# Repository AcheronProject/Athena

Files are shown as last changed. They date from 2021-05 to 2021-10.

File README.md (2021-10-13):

# Acheron Athena

## Introduction

Athena is a tenkeyless (TKL) keyboard Printed Circuit Board (PCB) which main feature is the multi-layout support. Athena supports:

- 87 (F12) or 88 (F13) TKL function rows;
- ANSI and ISO layouts
- 7U and 6.25U spacebar bottom row layouts
- Split backspace
- Split right shift

Below is a [Keyboard Layout Editor](http://keyboard-layout-editor.com/) image of the layouts Athena supports.

Athena KLE

In [this link](https://raw.githubusercontent.com/Gondolindrim/file_hosting/main/athena/athena_KLE.json) there is a KLE JSON file for the layout.

Both Apollo and Athena line of PCBs were designed to be "universal" TKL PCBs, that is, designed to fit a wide variety of custom mechanical keyboards. The compatibility list is being built as more people check and test. See the **Keyboard compatibility** section of this README for the available list.

## Technical information

- Layout size: tenkeykess (TKL)
- Compatible switches: MX-like only, solderable
- Lighting: single colors per-key through-hole LEDs, RGB underglow
- Microcontroller: STM32 family (see [the Joker topologyt documentaton](https://acheronproject.com/multimcu_article/multimcu_article/))
- Connector: detachable USB Type C on the top side and JST connector for daughterboard support
- Firmware compatibility: QMK (with VIA support)
- Protection hardware:
  * USB data lines and power rail ESD suppressing
  * USB power overvoltage protection
  * Enclosure grounding pad
  * Overcurrent protection
  * LDO crowbar diode
  * EMI suppression (shielding ferrite bead)
- Current release: release Alpha-RC1 (pre-release candidate)
- Designer: Gondolindrim
- License: Acheron Open-Source Hardware License version 1.3

## Keyboard compatibility

## Known compatibilities

- **Geonworks F1-8X and F1-6X:** confirmed by Geon, who tested the PCB 3D files against the case 3D files. Live hardware testing into a machined case is pending.

### Known incompatibilities

- **ai03 KBD8X MKII**: ai03 open-sourced the PCB files for his KBD8X. Alghtough Apollo's edges do fit inside the original PCB's, its connector is more protruded then the original PCB's.

- **PrismA18**: different layouts on the function row.

## Acknowledgements

- Geon, who kindly spent time helping design this PCB to fit his keyboards.

## Copyright notice

This project is released under the Acheron Open-Hardware License V1.3. For the license, please refer to the LICENCE.md file.

The "athena with shield" logo was licensed through Adobe Stock in [this link](https://stock.adobe.com/hu/images/greek-goddess-athena-illustration/157297137); the source file in Adobe Illustrator format, with a converted ``.svg`` format  can be found in ``./resources/athena_logo``. The license was obtained in may 06, 2021 and allows the AcheronProject to redistribute the logo as open-source and allows anyone to sell the PCBs commercially, but it does not allow for reproduction, meaning that if you want to use the logo for your designs or products you will have to buy a license yourself.

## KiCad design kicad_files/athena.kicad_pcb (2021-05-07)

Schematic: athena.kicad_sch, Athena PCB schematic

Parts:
C1, C2, C7: 100n; C_0805_2012Metric
C3, C4, C5, C13: 100n; C_0402_1005Metric
C6, C14: 4.7u; C_0402_1005Metric
C8: 1u; C_0402_1005Metric
C9: 10n; C_0402_1005Metric
C10, C11: 1u; CP_EIA-3216-10_Kemet-I_Pad1.58x1.35mm_HandSolder
C12: 10u; C_0805_2012Metric
D1, D2, D3, D4, D5, D6, D7, D8, D9, D10, D11, D12, D13, D14, D15, D16, D17, D18, D19, D20, D21, D22, D23, D24, D25, D26, D27, D28, D29, D30, D31, D32, D33, D34, D35, D36, D37, D38, D39, D40, D41, D42, D43, D44, D45, D46, D47, D48, D49, D50, D51, D52, D53, D54, D55, D56, D57, D58, D59, D60, D61, D62, D63, D64, D65, D66, D67, D68, D69, D70, D71, D72, D73, D74, D75, D76, D77, D78, D79, D80, D81, D82, D83, D84, D85, D86, D87, D88, D89, D90, D91, D92, D94: 1N4148W; D_SOD-123
D93: RB060M-60TR; D_SOD-123; Manufacturer Part Number RB060M-60TR; LCSC Part Number C114257
F1: mSMD110-16V; Fuse_1812_4532Metric; Manufacturer Part Number mSMD110-16V; LCSC Part Number C69691
FB1: CBW201209U121T; L_0805_2012Metric; Manufacturer Part Number CBW201209U121T; LCSC Part Number C139186
H1: MountingHole; MountingHole_2.5x4.0mm
J1, J3: SM04B-SRSS-TB(LF)(SN); SM04B-SRSS-TB(LF)(SN)_mounting-reliefs; Manufacturer Part Number SM04B-SRSS-TB(LF)(SN); LCSC Part Number C160404
J2: TYPE-C-31-M12; TYPE-C-31-M-12; Manufacturer Part Number TYPE-C-31-M-12; LCSC Part Number C165948
J4: ARM JTAG; Conn_ARM_JTAG_SWD_6
J5: EXTRA PINS; PinHeader_1x5_P2.54mm_Vertical
Q1: DTC123JKAT146; SOT-23; Manufacturer Part Number DTC123JKAT146; LCSC Part Number C111724
R1: 10k; R_0805_2012Metric
R2, R3: 5.1k; R_0805_2012Metric
R4, R5: 1.5k; R_0402_1005Metric
R6: 100R; R_0805_2012Metric
R7, R8: 100k; R_0805_2012Metric
R9: 330k; R_0805_2012Metric
R10: 1M; R_0805_2012Metric
SW1, SW2, SW3, SW4, SW5, SW6, SW7, SW8, SW9, SW10, SW11, SW12, SW13, SW14, SW15, SW16, SW17, SW18, SW19, SW20, SW21, SW22, SW23, SW24, SW25, SW26, SW27, SW28, SW29, SW30, SW31, SW32, SW33, SW34, SW35, SW36, SW37, SW38, SW40, SW41, SW43, SW44, SW45, SW46, SW47, SW48, SW49, SW50, SW51, SW52, SW53, SW54, SW56, SW57, SW58, SW60, SW61, SW62, SW63, SW64, SW65, SW66, SW67, SW68, SW69, SW70, SW71, SW73, SW74, SW75, SW79, SW80, SW81, SW82, SW83, SW84, SW85, SW86, SW87, SW88, SW89, SW91, SW92, SW103, SW104, SW105, SW107, SW111: MX Switch; MX100
SW39: MX Switch; MX200
SW42, SW55, SW106, SW108, SW110, SW112: MX Switch; MX150
SW59, SW93: MX Switch; MX175
SW72: MX Switch; MX225R
SW76, SW94, SW95, SW96, SW97, SW99, SW100, SW101, SW102: MX Switch; MX125
SW77: MX Switch; MX_ISOEnter_Horizontal
SW78: MX Switch; MX225
SW90: MX Switch; MX275
SW98: MX Switch; MX625R
SW109: MX Switch; MX700R
SW113: K2-1187SQ-A4SW-06; Manufacturer Part Number K2-1187SQ-A4SW-06; LCSC Part Number C92584
U1: TXS0101DBVR; SOT-23-6; Manufacturer Part Number TXS0101DBVR; LCSC Part Number C132604
U2: USBLC6-2SC6; SOT-23-6; Manufacturer Part Number USBLC6-2SC6; LCSC Part Number C7519
U3: STM32F072CBT6; LQFP-48_7x7mm_P0.5mm; Manufacturer Part Number STM32F072CBT6; LCSC Part Number C81720
U4: MCP1700T-3302E/TT; SOT-23; Manufacturer Part Number MCP1700T-3302E/TT; LCSC Part Number C39051

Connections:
3V3: C1.2, C3.1, C4.1, C5.2, C6.2, C8.1, C9.1, C11.1, C13.2, C14.2, D93.2 (A), J4.1, J5.4, R1.1, R4.1, R5.1, R8.1, SW113.1 (A), U1.1 (VCCA), U3.1 (VBAT), U3.9 (VDDA), U3.24 (VDD), U3.36 (VDDIO2), U3.48 (VDD), U4.2 (VO)
5V: C2.1, C10.1, D93.1 (K), F1.2, J1.1, J3.1, R7.1, U1.6 (VCCB), U4.3 (VI)
BOOT0: C12.2, J4.6, R9.2, R10.2, U3.44 (BOOT0)
C0: SW1.2, SW26.2, SW42.2, SW59.2, SW76.1, SW78.2, SW94.2, SW95.2, SW106.2, U3.16 (PA6/ADC_IN6/TIM3_CH1/TIM16_CH1)
C1: SW2.1, SW27.1, SW43.1, SW60.1, SW79.1, SW96.1, SW107.1, U3.15 (PA5/ADC_IN5/DAC_OUT2)
C2: SW3.1, SW18.2, SW28.1, SW44.1, SW61.1, SW80.1, SW97.1, SW108.1, U3.14 (PA4/TIM14_CH1/ADC_IN4)
C3: SW4.1, SW19.2, SW29.1, SW45.1, SW62.1, SW81.1, U3.13 (PA3/TIM15_CH2/ADC_IN3)
C4: SW5.1, SW20.2, SW30.1, SW46.1, SW63.1, SW82.1, U3.12 (PA2/ADC_IN2)
C5: SW6.1, SW21.2, SW31.1, SW47.1, SW64.1, SW83.1, U3.40 (SPI1_MISO/I2S1_MCK/TIM3_CH1/PB4)
C6: SW7.1, SW32.1, SW48.1, SW65.1, SW84.1, SW98.2, SW109.2, U3.39 (SPI1_SCK/I2S1_CK/TIM2_CH2/PB3)
C7: SW8.1, SW33.1, SW49.1, SW66.1, SW85.1, U3.38 (PA15)
C8: SW9.1, SW34.1, SW50.1, SW67.1, SW86.1, U3.30 (TIM1_CH2/PA9)
C9: SW10.1, SW22.2, SW35.1, SW51.1, SW68.1, SW87.1, SW99.2, SW110.2, U3.29 (TIM1_CH1/PA8)
C10: SW11.2, SW23.1, SW36.1, SW52.1, SW69.1, SW88.1, SW100.2, U3.27 (SPI2_MISO/I2S2_MCK/I2C2_SDA/TIM15_CH1/P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)
C11: SW12.2, SW24.1, SW37.1, SW53.1, SW70.1, SW89.1, SW101.2, U3.25 (PB12)
C12: SW13.2, SW25.1, SW38.1, SW54.1, SW71.1, SW90.1, SW93.1, U3.21 (PB10/SPI2_SCK/I2C2_SCL/TIM2_CH3)
C13: SW14.1, SW39.1, SW41.1, SW55.1, SW72.1, SW77.1, SW91.1, SW102.1, SW112.1, U3.31 (TIM1_CH3/PA10)
C14: SW15.2, SW40.1, SW56.2, SW73.2, SW103.1, U3.10 (PA0/ADC_IN0)
C15: SW16.1, SW57.1, SW74.1, SW92.1, SW104.2, U3.5 (PF0/OSC_IN)
C16: SW17.1, SW58.1, SW75.1, SW105.1, U3.6 (PF1/OSC_OUT)
D+: J3.3, U2.1 (I/O1), U3.33 (USB_DP/PA12)
D-: J3.2, U2.3 (I/O2), U3.32 (USB_DM/TIM1_CH4/PA11)
DBUS+: J2.A6 (D+), J2.B6 (D+), U2.6 (I/O1)
DBUS-: J2.A7 (D-), J2.B7 (D-), U2.4 (I/O2)
GND: C1.1, C2.2, C3.2, C4.2, C5.1, C6.1, C7.2, C8.2, C9.2, C10.2, C11.2, C12.1, C13.1, C14.1, FB1.1, J1.2, J1.4, J1.MP (MountPin), J2.A1 (GND), J2.B1 (GND), J3.4, J3.MP (MountPin), J4.5, J5.5, Q1.2 (E), R2.1, R3.1, R7.2, R8.2, R10.1, U1.2 (GND), U2.2 (GND), U3.8 (VSSA), U3.23 (VSS), U3.35 (VSS), U3.47 (VSS), U4.1 (GND)
GNDPWR: FB1.2, H1.1, J2.S (SHIELD)
INTB: U3.45 (I2C1_SCL/TIM16_CH1/PB8)
NRST: C7.1, J4.3, R6.2, U3.7 (NRST)
unnamed: D1.2 (A), SW1.1
unnamed: D2.2 (A), SW2.2
unnamed: D3.2 (A), SW3.2, SW18.1
unnamed: D4.2 (A), SW4.2, SW19.1
unnamed: D5.2 (A), SW5.2, SW20.1
unnamed: D6.2 (A), SW6.2, SW21.1
unnamed: D7.2 (A), SW7.2
unnamed: D8.2 (A), SW8.2
unnamed: D9.2 (A), SW9.2
unnamed: D10.2 (A), SW10.2, SW22.1
unnamed: D11.2 (A), SW11.1, SW23.2
unnamed: D12.2 (A), SW12.1, SW24.2
unnamed: D13.2 (A), SW13.1, SW25.2
unnamed: D14.2 (A), SW14.2
unnamed: D15.2 (A), SW15.1
unnamed: D16.2 (A), SW16.2
unnamed: D17.2 (A), SW17.2
unnamed: D18.2 (A), SW26.1
unnamed: D19.2 (A), SW27.2
unnamed: D20.2 (A), SW28.2
unnamed: D21.2 (A), SW29.2
unnamed: D22.2 (A), SW30.2
unnamed: D23.2 (A), SW31.2
unnamed: D24.2 (A), SW32.2
unnamed: D25.2 (A), SW33.2
unnamed: D26.2 (A), SW34.2
unnamed: D27.2 (A), SW35.2
unnamed: D28.2 (A), SW36.2
unnamed: D29.2 (A), SW37.2
unnamed: D30.2 (A), SW38.2
unnamed: D31.2 (A), SW39.2, SW41.2
unnamed: D32.2 (A), SW40.2
unnamed: D33.2 (A), SW42.1
unnamed: D34.2 (A), SW43.2
unnamed: D35.2 (A), SW44.2
unnamed: D36.2 (A), SW45.2
unnamed: D37.2 (A), SW46.2
unnamed: D38.2 (A), SW47.2
unnamed: D39.2 (A), SW48.2
unnamed: D40.2 (A), SW49.2
unnamed: D41.2 (A), SW50.2
unnamed: D42.2 (A), SW51.2
unnamed: D43.2 (A), SW52.2
unnamed: D44.2 (A), SW53.2
unnamed: D45.2 (A), SW54.2
unnamed: D46.2 (A), SW55.2
unnamed: D47.2 (A), SW56.1
unnamed: D48.2 (A), SW57.2
unnamed: D49.2 (A), SW58.2
unnamed: D50.2 (A), SW59.1, SW76.2
unnamed: D51.2 (A), SW60.2
unnamed: D52.2 (A), SW61.2
unnamed: D53.2 (A), SW62.2
unnamed: D54.2 (A), SW63.2
unnamed: D55.2 (A), SW64.2
unnamed: D56.2 (A), SW65.2
unnamed: D57.2 (A), SW66.2
unnamed: D58.2 (A), SW67.2
unnamed: D59.2 (A), SW68.2
unnamed: D60.2 (A), SW69.2
unnamed: D61.2 (A), SW70.2
unnamed: D62.2 (A), SW71.2
unnamed: D63.2 (A), SW72.2, SW77.2
unnamed: D64.2 (A), SW73.1
unnamed: D65.2 (A), SW74.2
unnamed: D66.2 (A), SW75.2
unnamed: D67.2 (A), SW78.1, SW94.1
unnamed: D68.2 (A), SW79.2
unnamed: D69.2 (A), SW80.2
unnamed: D70.2 (A), SW81.2
unnamed: D71.2 (A), SW82.2
unnamed: D72.2 (A), SW83.2
unnamed: D73.2 (A), SW84.2
unnamed: D74.2 (A), SW85.2
unnamed: D75.2 (A), SW86.2
unnamed: D76.2 (A), SW87.2
unnamed: D77.2 (A), SW88.2
unnamed: D78.2 (A), SW89.2
unnamed: D79.2 (A), SW90.2, SW93.2
unnamed: D80.2 (A), SW91.2
unnamed: D81.2 (A), SW92.2
unnamed: D82.2 (A), SW95.1, SW106.1
unnamed: D83.2 (A), SW96.2, SW107.2
unnamed: D84.2 (A), SW97.2, SW108.2
unnamed: D85.2 (A), SW98.1, SW109.1
unnamed: D86.2 (A), SW99.1, SW110.1
unnamed: D87.2 (A), SW100.1
unnamed: D88.2 (A), SW101.1
unnamed: D89.2 (A), SW102.2, SW112.2
unnamed: D90.2 (A), SW103.2
unnamed: D91.2 (A), SW104.1
unnamed: D92.2 (A), SW105.2
unnamed: D94.1 (K), R9.1
unnamed: D94.2 (A), Q1.1 (B), SW113.2 (B)
unnamed: J2.A5 (CC1), R2.2
unnamed: J2.B5 (CC2), R3.2
unnamed: Q1.3 (C), R6.1
unnamed: R1.2, U1.5 (OE)
PC13: J5.1, U3.2 (PC13)
PC14: J5.2, U3.3 (PC14/OSC32_IN)
PC15: J5.3, U3.4 (PC15/OSC32_OUT)
R0: D1.1 (K), D2.1 (K), D3.1 (K), D4.1 (K), D5.1 (K), D6.1 (K), D7.1 (K), D8.1 (K), D9.1 (K), D10.1 (K), D11.1 (K), D12.1 (K), D13.1 (K), D14.1 (K), D15.1 (K), D16.1 (K), D17.1 (K), U3.18 (PB0/TIM3_CH3/ADC_IN8)
R1: D18.1 (K), D19.1 (K), D20.1 (K), D21.1 (K), D22.1 (K), D23.1 (K), D24.1 (K), D25.1 (K), D26.1 (K), D27.1 (K), D28.1 (K), D29.1 (K), D30.1 (K), D31.1 (K), D32.1 (K), U3.19 (PB1/TIM3_CH4/TIM14_CH1/ADC_IN9)
R2: D33.1 (K), D34.1 (K), D35.1 (K), D36.1 (K), D37.1 (K), D38.1 (K), D39.1 (K), D40.1 (K), D41.1 (K), D42.1 (K), D43.1 (K), D44.1 (K), D45.1 (K), D46.1 (K), D47.1 (K), D48.1 (K), D49.1 (K), U3.20 (PB2)
R3: D50.1 (K), D51.1 (K), D52.1 (K), D53.1 (K), D54.1 (K), D55.1 (K), D56.1 (K), D57.1 (K), D58.1 (K), D59.1 (K), D60.1 (K), D61.1 (K), D62.1 (K), D63.1 (K), D64.1 (K), D65.1 (K), D66.1 (K), U3.22 (PB11/TIM2_CH4/I2C2_SDA)
R4: D67.1 (K), D68.1 (K), D69.1 (K), D70.1 (K), D71.1 (K), D72.1 (K), D73.1 (K), D74.1 (K), D75.1 (K), D76.1 (K), D77.1 (K), D78.1 (K), D79.1 (K), D80.1 (K), D81.1 (K), U3.11 (PA1/ADC_IN1)
R5: D82.1 (K), D83.1 (K), D84.1 (K), D85.1 (K), D86.1 (K), D87.1 (K), D88.1 (K), D89.1 (K), D90.1 (K), D91.1 (K), D92.1 (K), U3.17 (PA7/TIM3_CH2/TIM14_CH1/ADC_IN7)
RGB_3V3: U1.3 (A), U3.28 (SPI2_MOSI/I2S2_SD/PB15)
RGB_5V: J1.3, U1.4 (B)
SCL: R5.2, U3.42 (I2C1_SCL/PB6)
SDA: R4.2, U3.43 (2C1_SDA/PB7)
SDB: U3.41 (SPI1_MOSI/I2S1_SD/TIM3_CH2/PB5)
SWCLK: J4.4, U3.37 (SWCLK/PA14)
SWDIO: J4.2, U3.34 (SWDIO/PA13)
VBUS: F1.1, J2.A4 (VBUS), J2.B4 (VBUS), U2.5 (VBUS)

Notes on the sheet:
USB Connector
USB ESD
MCU
SWITCH MATRIX
3V3
RGB STRIP
HARD RESET

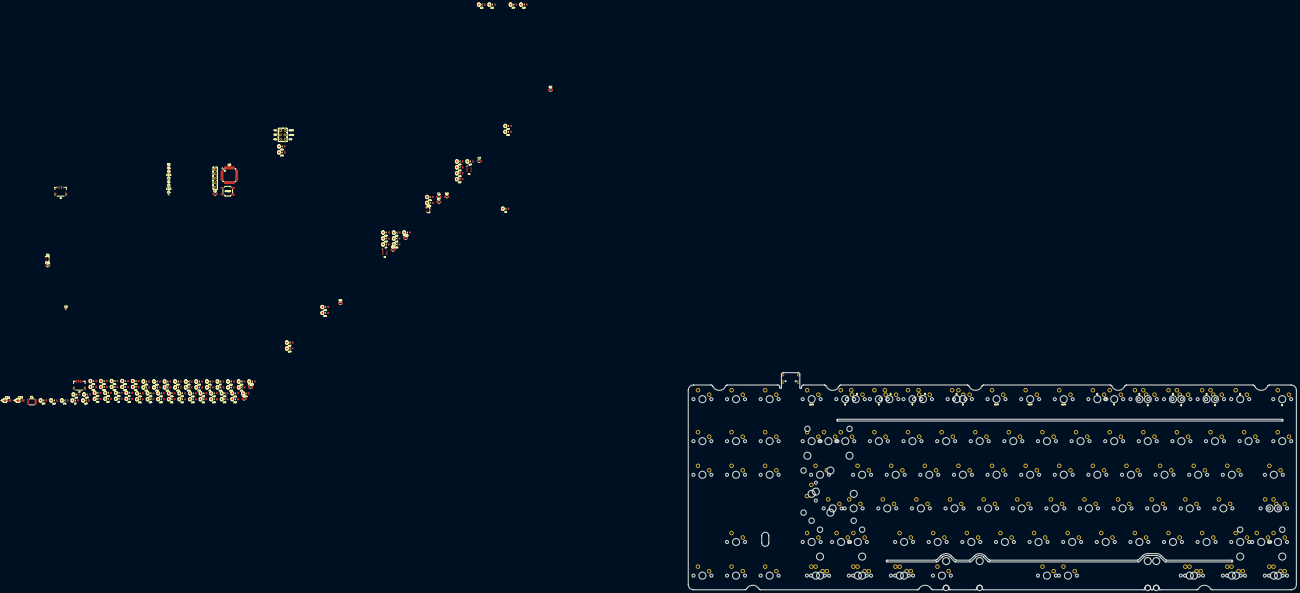
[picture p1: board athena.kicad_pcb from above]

Board: 2 copper layers, 344.7 x 123.1 mm, 242 parts (1 on the bottom side), 140 nets, no tracks yet.

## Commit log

2021-05-07 Further developments
    - Define PCB edges
    - Place switches and layouts
    - Place USBC connector
    [athena.kicad_pcb, athena.kicad_sch]
2021-05-07 Added Athena logo
    [athena.kicad_sch]
2021-05-08 Route first row and most USB, add LEDs
2021-09-25 Acheron Setup port, joker topology
    - Tolerances and constraints were updated to Acheron Setup's defaults
    - New MCU "joker" topology
    [athena.kicad_sch]
2021-09-26 Routing work
    [athena.kicad_sch]
2021-09-27 Routing work, USB DB sketch
    [athena.kicad_sch]
2021-09-28 More routing, DRC and post-routing pending
    [athena.kicad_sch]
2021-10-01 Added logos, some DRC
    [athena.kicad_sch]
2021-10-02 Add warning signs, DRC ran, errors fixed
    [athena.kicad_sch]
2021-10-05 MCU circuit topology, QOL updates
    - Both RCC resistors for USB are now in the bottom layer
    - DRC ran again, no errors found
    - Changed MCU template to the joker revision 2, meaning removal of some bypass capacitors, adittion of a tantallum 10uF capacitor for VDD and change VCAP pin capacitor to 4.7uF from 2.2uF
    [athena.kicad_sch]
2021-10-09 Implement B87X2 outline
    [athena.kicad_sch]
2021-10-10 Documented outline, DRC
    - Outline is now B87-based and contains gummy mount holes all througout the layouts. Outline is also documented containing angles and centers.
    - DRC performed, changes and corrections made
    [athena.kicad_sch]
2021-10-12 Update component metadata
    [athena.kicad_sch]
2021-12-07 Re-routes, optimizations, corrections
    - Re-routed rows R4 and R5; SWCLK pin confirmedly works as row pin as tested on pre-revision Alpha prototypes
    - Removec trace stubs on bottom left
    - Small traces optimization
    [athena.kicad_sch]
2021-12-09 a-RC1 label, digital transistors
    - Label was changed to Alpha-RC1 version
    - Instead of relying on MCU open-drain pins, discrete digital NPN transistors were added to the caps lock indicator control and backlight PWM opendrain circuit
    [athena.kicad_sch]
2021-12-18 Start porting to 64 pin MCU
    [athena.kicad_sch]
2021-12-18 Grounding improvements
    - Grounding around MCU USB traces and connector was improved
    - For this, a couple traces were moved around, as well as a few components, most importantly the ESD chip
2021-12-18 hange LDO caps to MLCC
    [athena.kicad_sch]
2021-12-18 Better grounding on top row
    - Moved traces and components for grounding pour integrity
2021-12-19 Update libs, route extra pins
    [athena.kicad_sch]
2021-12-19 Add some extra pins
    [athena.kicad_sch]
2021-12-19 Finish adding extra pins
    [athena.kicad_sch]
2021-12-19 Adjust USB 5V routing
    [athena.kicad_sch]
2021-12-19 New tag
    [athena.kicad_sch]
2022-01-20 DRC, RGB pins
    - DRC ran, small errors corrected
    - RGB out pins from RGB DB JST connector were broken out
    - 2.0.1-2.0.1 tag
    [athena.kicad_sch]
2022-01-20 Move 2nd row LED resistors for better grounding
    [athena.kicad_sch]
2022-01-24 Trace improvements
2022-01-28 Start porting design to JLCPCB-compliant parts
    [athena.kicad_sch]
2022-01-28 Corrections for some DRC issues
    [athena.kicad_sch]
2022-01-28 More DRC corrections
    [athena.kicad_sch]
2022-01-29 Add metadata to components
    [athena.kicad_sch]
2022-01-29 DRC corrections, metadata add
    - Added LCSC number for missing components
    - DRC corrections: diodes courtyard overlaps
    [athena.kicad_sch]
2022-01-29 Edit component metadata
    [athena.kicad_sch]
2022-02-04 RGB translator change
    RGB translator changed from SC-70-6 version to SOT-563 due to JLC shortage of the former
    [athena.kicad_sch]
2022-02-04 Edit component metadata; prepare for release
    [athena.kicad_sch]
2022-04-05 Move top row resistors
2022-04-05 Remove RC1 from label
    [athena.kicad_sch]
2022-04-07 DRC ran, errors corrected. Added outline cuts for H87/88 compatibility
    [athena.kicad_sch]
2022-04-11 Update PCB with metadata
